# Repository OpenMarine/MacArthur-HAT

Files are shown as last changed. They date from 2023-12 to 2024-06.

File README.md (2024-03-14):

# MacArthur-HAT

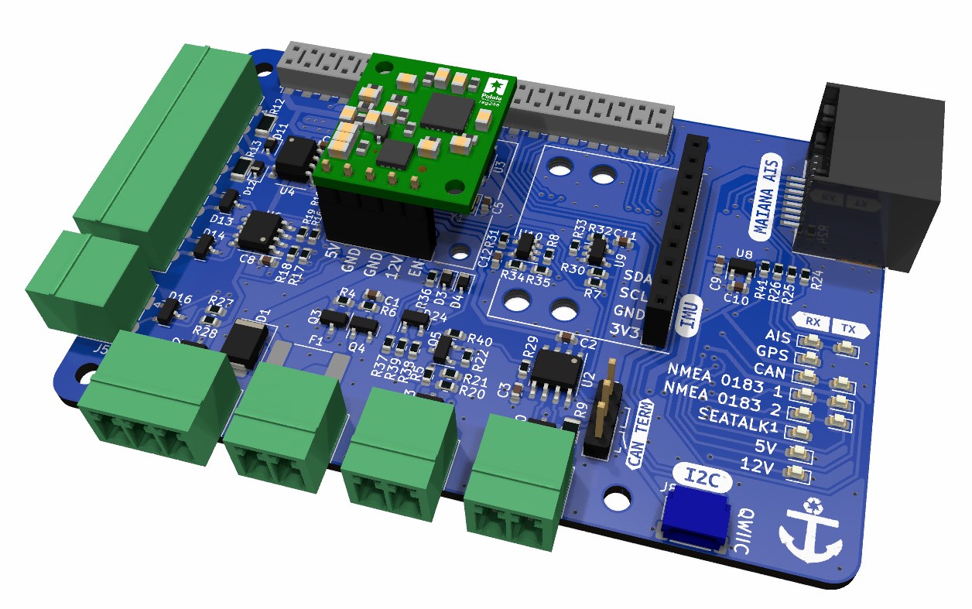
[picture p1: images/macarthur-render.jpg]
MacArthur-HAT


After a few years of developing software for **OpenPlotter**, we have identified exactly what we need in terms of hardware to achieve our goals and the result is the **MacArthur HAT** (Hardware Attached on Top), an add-on board for **Raspberry Pi** running OpenPlotter. With this HAT we want to get the fully open-source boat to free ourselves from dependence on big companies and make our boats more respectful with the environment.

> __Note__
>
> KiCad files will be released when the board is in production.

> __Documentation__
>
> http://macarthur-hat-documentation.rtfd.io

> __Buy__
>
> [**OpenMarine store** (Catalonia)](https://shop.openmarine.net/home/23-macarthur-hat.html)
> 
> [**Wegmatt store** (US)](https://shop.wegmatt.com/collections/openmarine)

> __Support__
>
> https://forum.openmarine.net/forumdisplay.php?fid=29

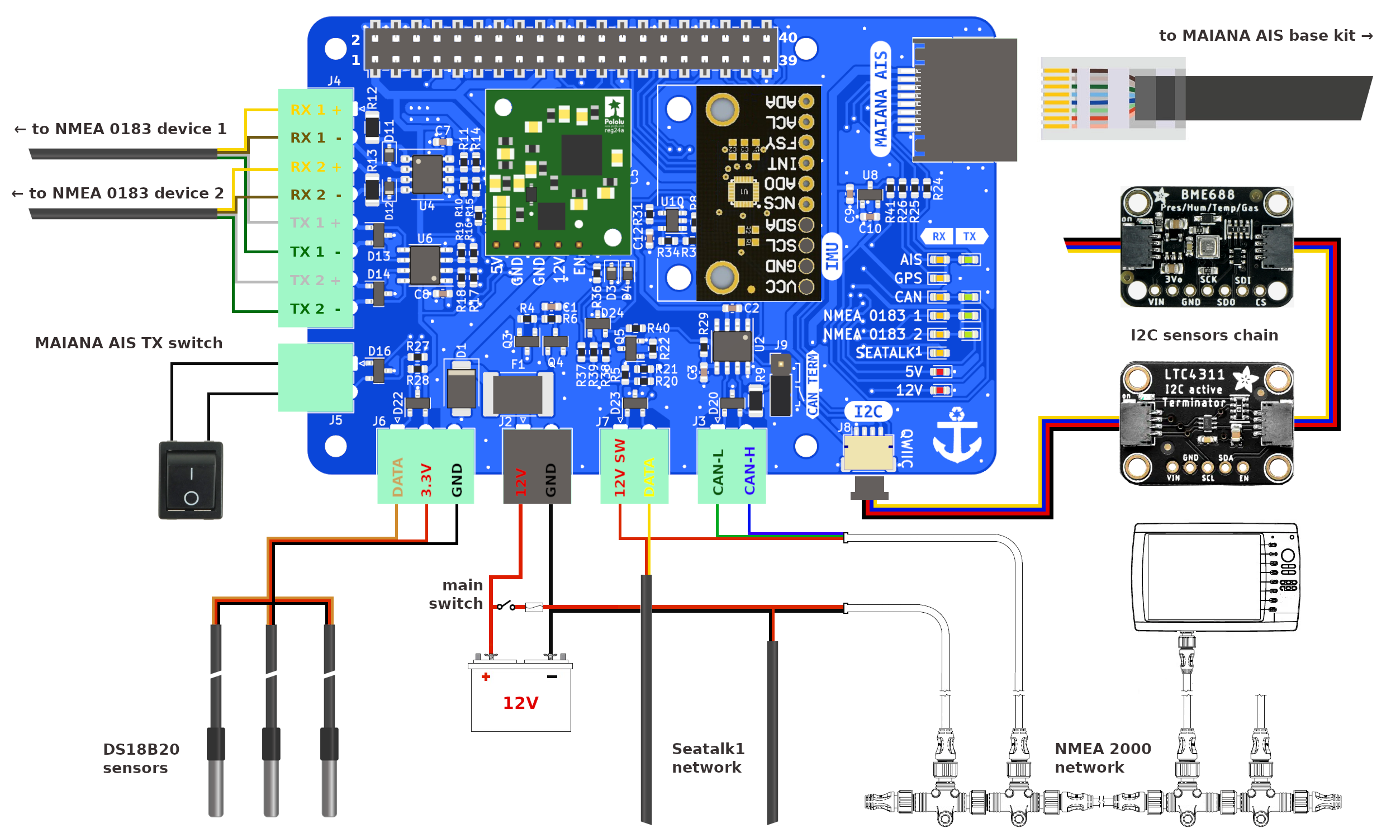
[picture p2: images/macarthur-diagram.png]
MacArthur-HAT


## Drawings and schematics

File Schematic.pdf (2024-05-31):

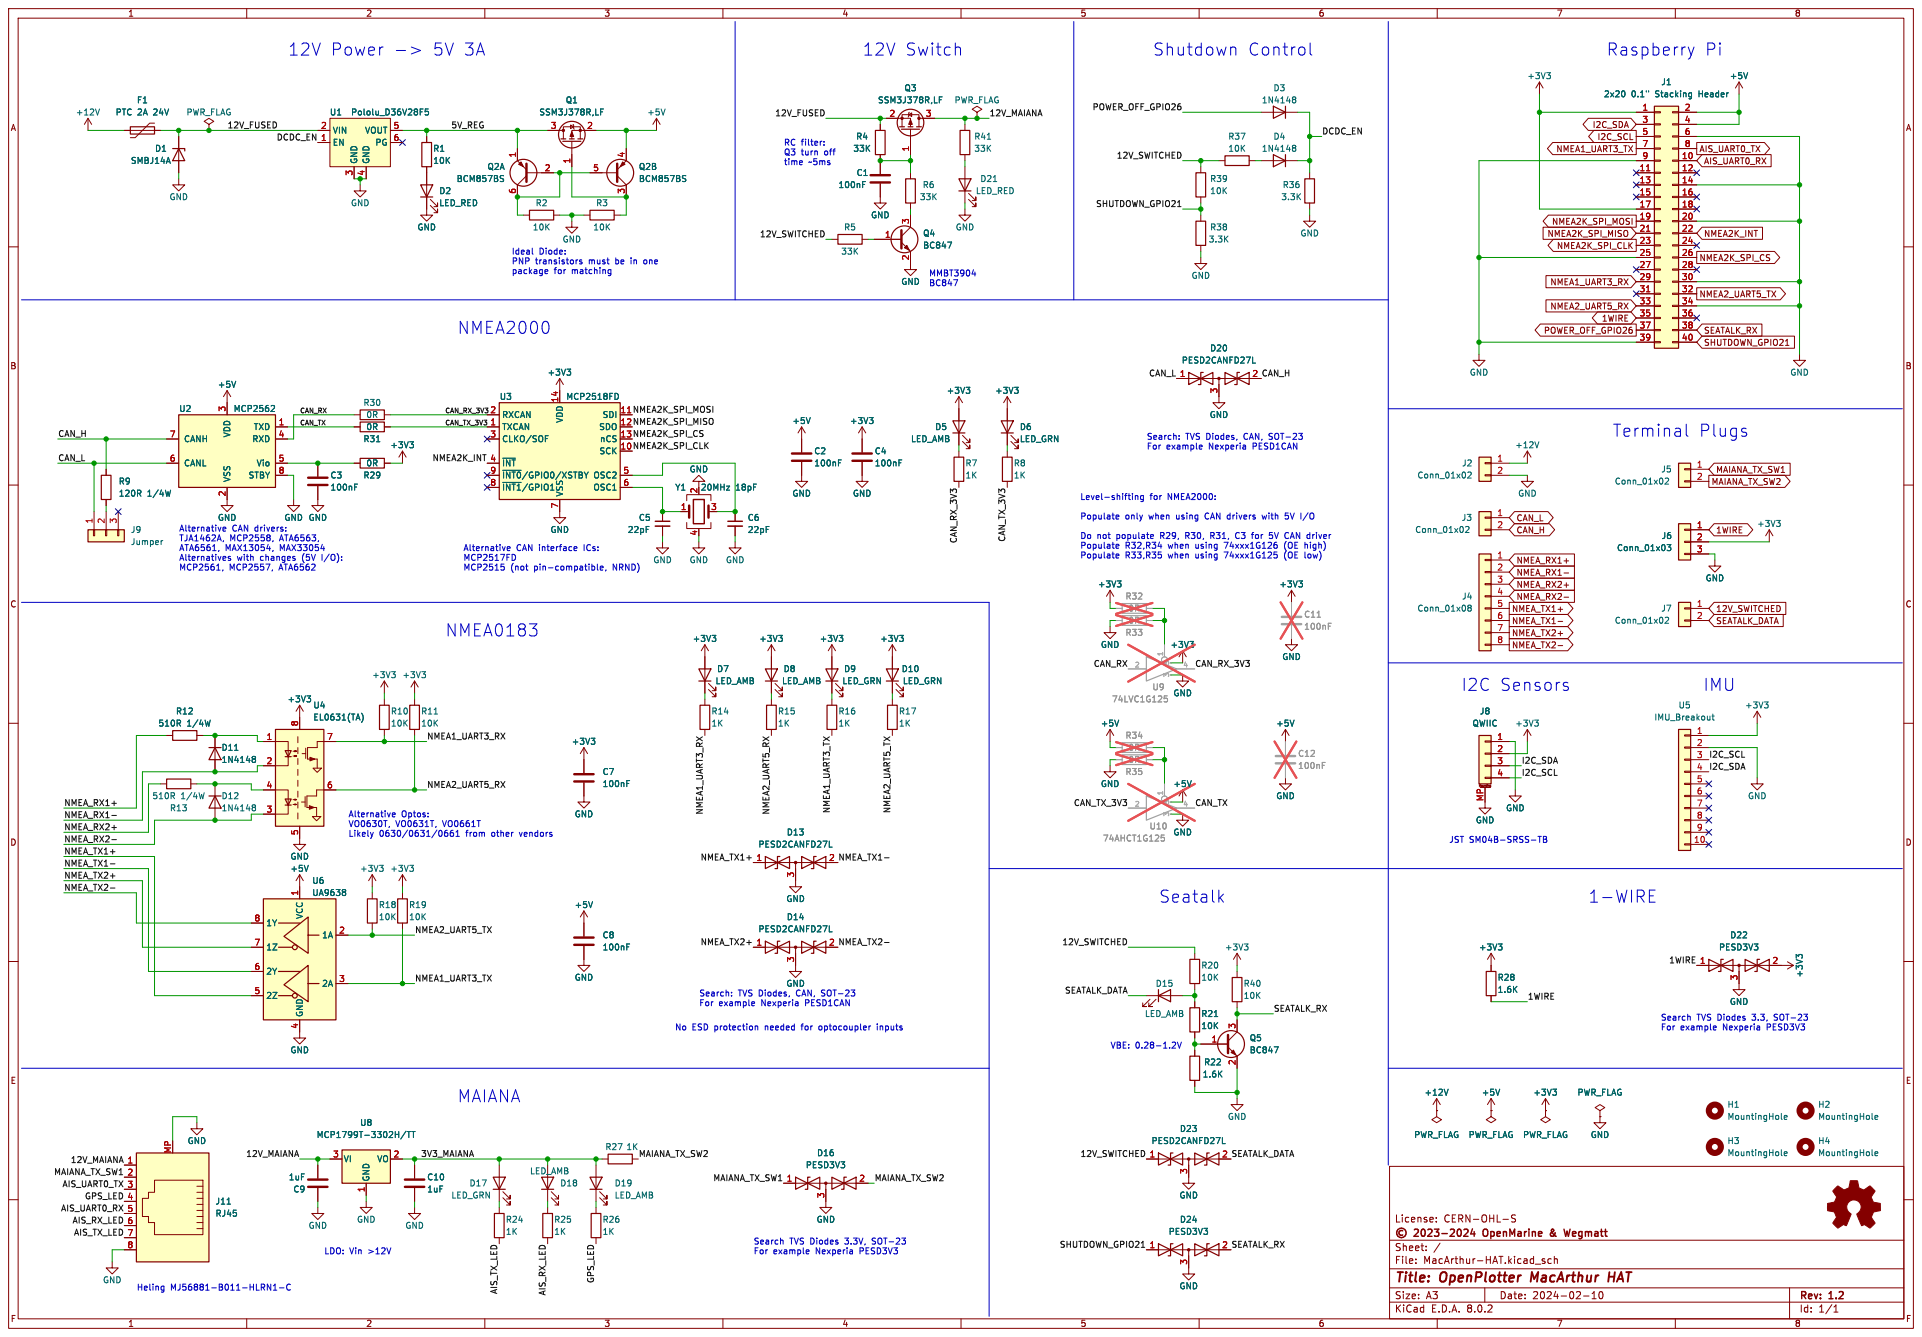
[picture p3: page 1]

Search: TVS Diodes, CAN, SOT-23 For example Nexperia PESD1CAN 12V Power -> 5V 3A

RC filter: Q3 turn off

3 RXD 4 Vio 5 CANL 6 CANH 7 STBY 8 GND GND GND GND

Search: TVS Diodes, CAN, SOT-23 For example Nexperia PESD1CAN NMEA2000

3 RXD 4 Vio 5 CANL 6 CANH 7 STBY 8 U2 MCP2562 +5V R29

Search TVS Diodes 3.3, SOT-23 For example Nexperia PESD3V3 Search TVS Diodes 3.3V, SOT-23 For example Nexperia PESD3V3

Id: 1/1 Title: OpenPlotter MacArthur HAT

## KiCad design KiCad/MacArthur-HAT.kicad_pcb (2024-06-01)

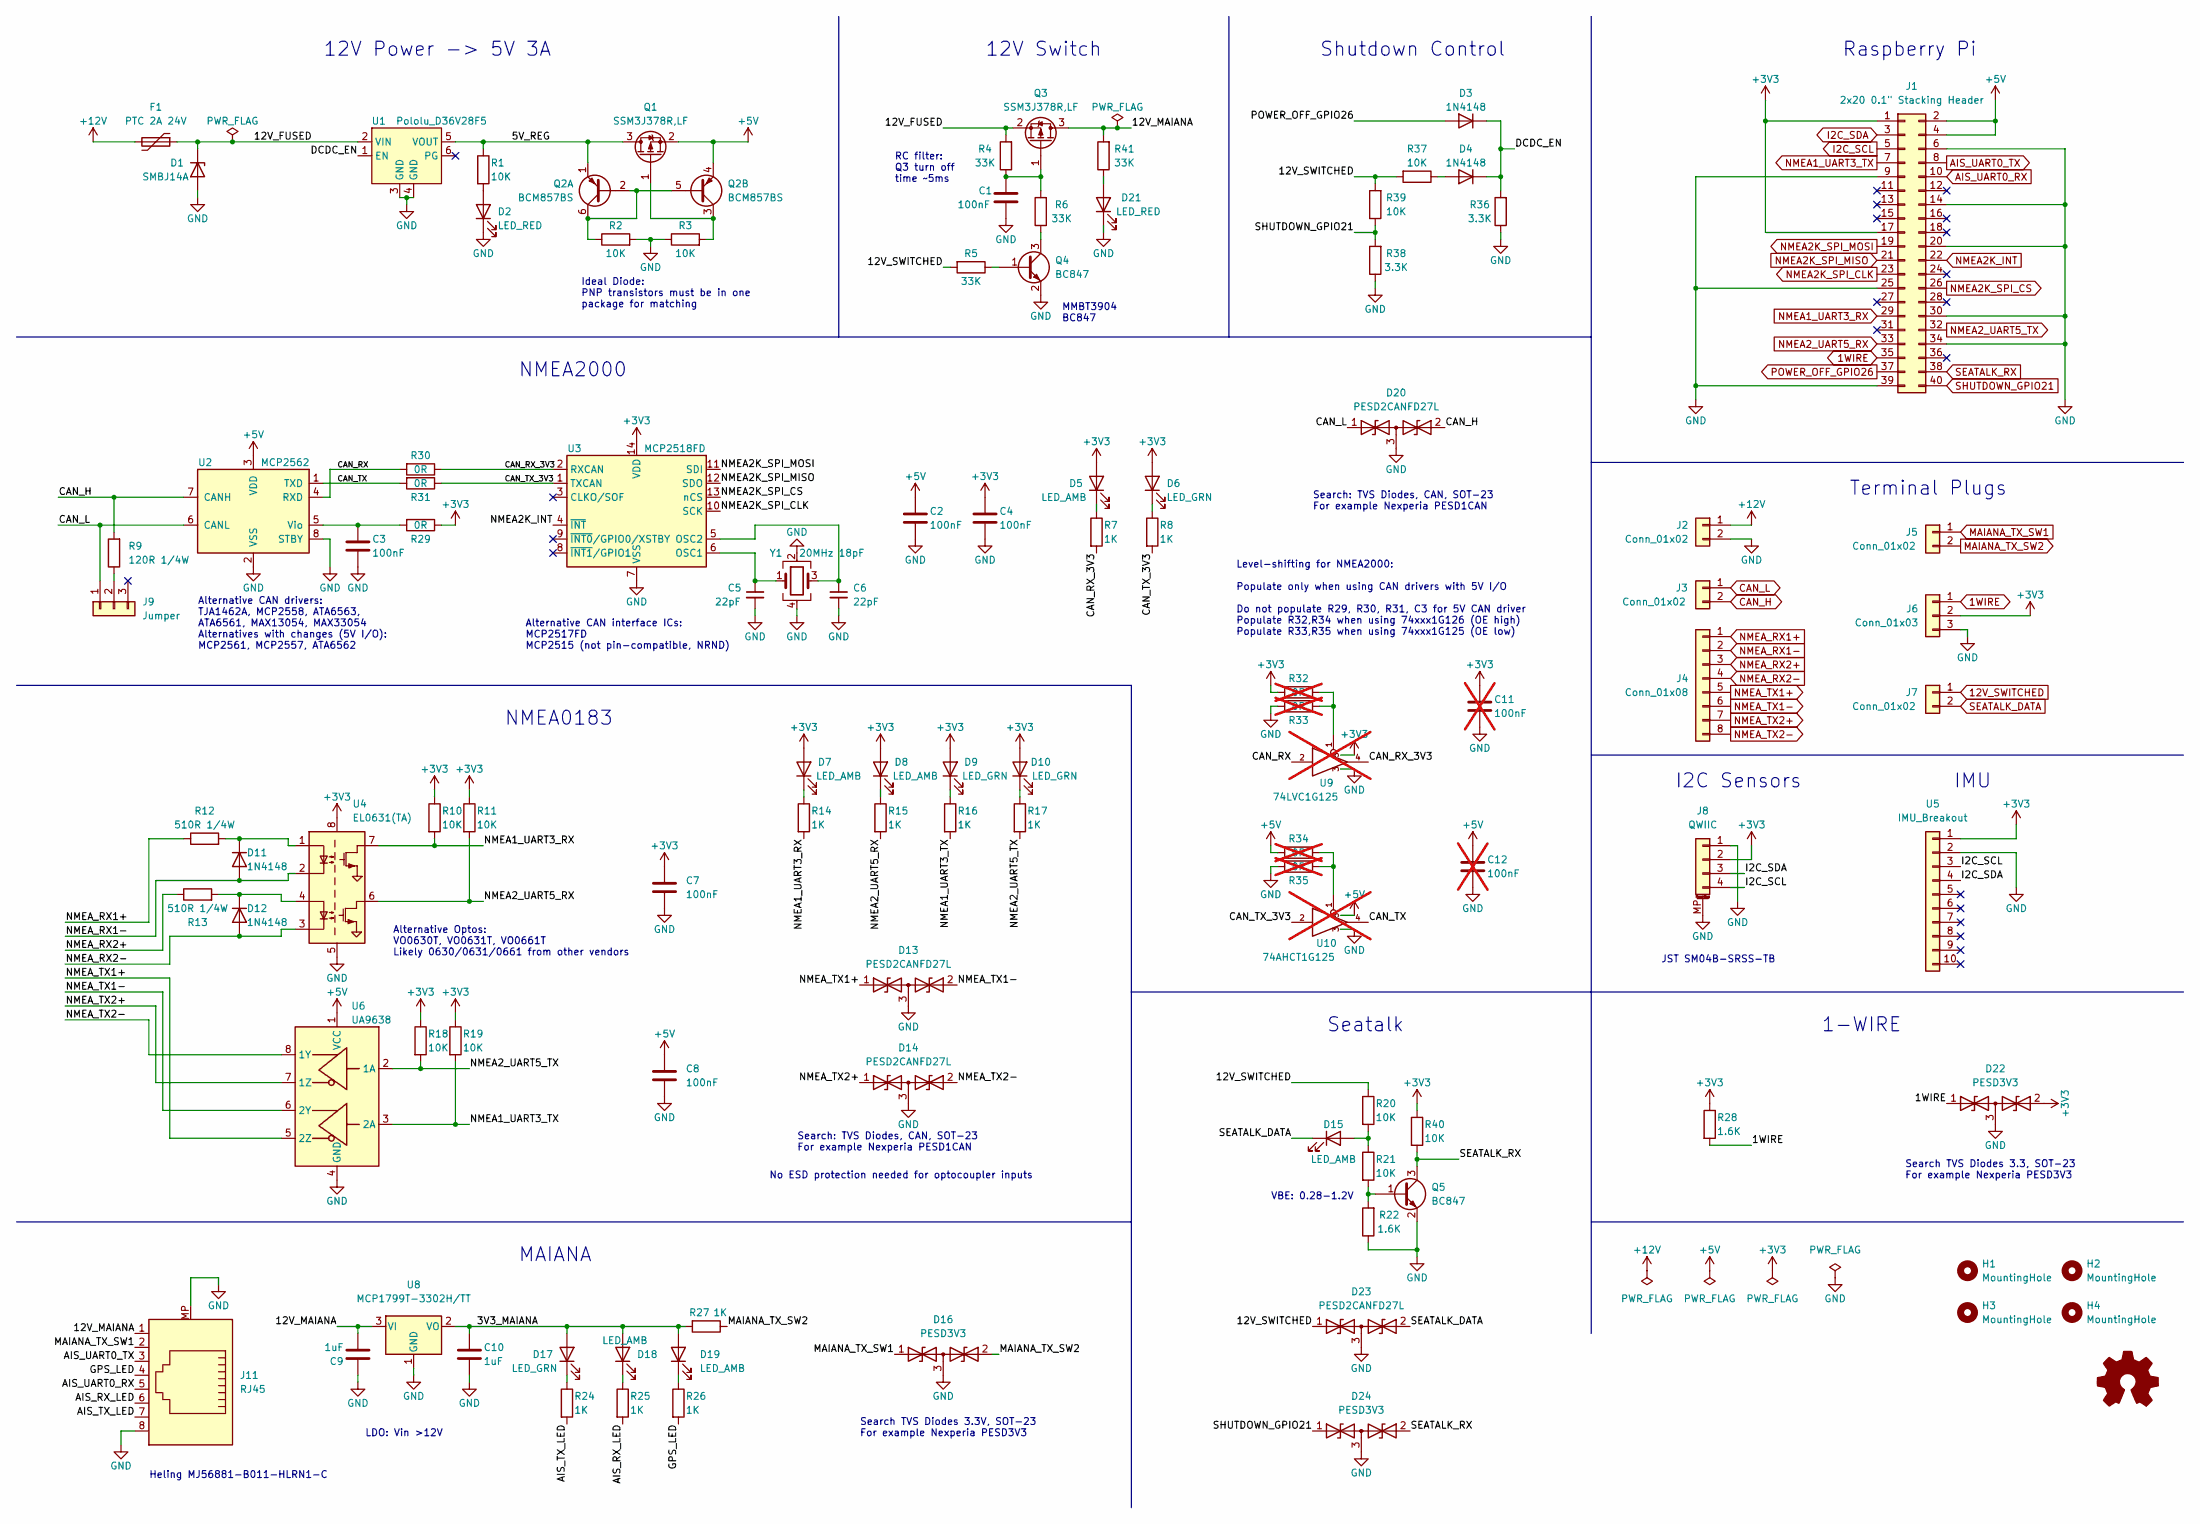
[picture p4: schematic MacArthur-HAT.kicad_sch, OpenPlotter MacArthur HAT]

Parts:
C1, C2, C3, C4, C7, C8: 100nF; C_0603_1608Metric
C5, C6: 22pF; C_0603_1608Metric
C9, C10: 1uF; C_0603_1608Metric
C11, C12: 100nF; C_0603_1608Metric; not fitted
D1: SMBJ14A; D_SMB; MPN SMBJ14A
D2, D21: LED_RED; LED_0603_1608Metric
D3, D4, D11, D12: 1N4148; D_SOD-323; MPN 1N4148WS
D5, D7, D8, D15, D18, D19: LED_AMB; LED_0603_1608Metric
D6, D9, D10, D17: LED_GRN; LED_0603_1608Metric
D13, D14, D20, D23: PESD2CANFD27L; SOT-23; MPN PESD2CAN
D16, D22, D24: PESD3V3; SOT-23; MPN PESD3V3S2UT,215
F1: PTC 2A 24V; Fuse_2920_7451Metric; MPN BSMD2920-200-24V
H1, H2, H3, H4: MountingHole; MountingHole_2.7mm_M2.5
J1: 2x20 0.1" Stacking Header; Raspberry_Pi_Stacking_Header
J2, J3, J5, J7: Conn_01x02; PhoenixContact_MC_1,5_2-G-3.5_1x02_P3.50mm_Horizontal
J4: Conn_01x08; PhoenixContact_MC_1,5_8-G-3.5_1x08_P3.50mm_Horizontal
J6: Conn_01x03; PhoenixContact_MC_1,5_3-G-3.5_1x03_P3.50mm_Horizontal
J8: QWIIC; JST_SH_SM04B-SRSS-TB_1x04-1MP_P1.00mm_Horizontal; MPN SM04B-SRSS-TB(LF)(SN)
J9: Jumper; PinHeader_1x03_P2.54mm_Vertical
J11: RJ45; RJ45-SMD_MJ56881-B011-HXRN1-C; MPN MJ56881-B011-HLRN1-C
LOGO1: Logo_Open_Hardware_Small; OSHW-Symbol_6.7x6mm_SilkScreen
Q1, Q3: SSM3J378R,LF; SOT-23; MPN SSM3J378R,LF
Q2: BCM857BS; SOT-363_SC-70-6; MPN BCM857BS
Q4, Q5: BC847; SOT-23; MPN BC847
R1, R2, R3, R10, R11, R18, R19, R20, R21, R37, R39, R40: 10K; R_0603_1608Metric
R4, R5, R6, R41: 33K; R_0603_1608Metric
R7, R8, R14, R15, R16, R17, R24, R25, R26, R27: 1K; R_0603_1608Metric
R9: 120R 1/4W; R_1206_3216Metric
R12, R13: 510R 1/4W; R_1206_3216Metric
R22, R28: 1.6K; R_0603_1608Metric
R29, R30, R31: 0R; R_0603_1608Metric
R32, R33, R34, R35: 0R; R_0603_1608Metric; not fitted
R36, R38: 3.3K; R_0603_1608Metric
U1: Pololu_D36V28F5; Pololu_D36V28Fx_reverse
U2: MCP2562; SOIC-8_3.9x4.9mm_P1.27mm; MPN MCP2562
U3: MCP2518FD; SOIC-14_3.9x8.7mm_P1.27mm; MPN MCP2518FD
U4: EL0631(TA); SOIC-8H_3.9x5.8mm_P1.27mm; MPN EL0631(TA)
U5: IMU_Breakout; CJMCU-96802-20948
U6: UA9638; SOIC-8_3.9x4.9mm_P1.27mm; MPN UA9638
U8: MCP1799T-3302H/TT; SOT-23; MPN MCP1799T-3302H/TT
U9: 74LVC1G125; SOT-23-5; not fitted
U10: 74AHCT1G125; SOT-23-5; not fitted
Y1: 20MHz 18pF; Crystal_SMD_3225-4Pin_3.2x2.5mm

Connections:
1WIRE: D22.1 (A1), J1.35, J6.1, R28.2
12V_SWITCHED: D23.1 (A1), J7.1, R5.2, R20.1, R37.2, R39.2
+3V3: C4.1, C7.1, C11.1, D5.2 (A), D6.2 (A), D7.2 (A), D8.2 (A), D9.2 (A), D10.2 (A), D22.2 (A2), J1.1, J1.17, J6.2, J8.2, R10.1, R11.1, R18.1, R19.1, R28.1, R29.1, R32.2, R40.1, U3.14 (VDD), U4.8 (VCC), U5.1, U9.5
+5V: C2.1, C8.1, C12.1, J1.2, J1.4, Q1.2 (S), Q2.4 (E2), R34.2, U2.3 (VDD), U6.1 (VCC), U10.5
+12V: F1.2, J2.1
/3V3_MAIANA: C10.1, D17.2 (A), D18.2 (A), D19.2 (A), R27.2, U8.2 (VO)
/5V_REG: Q1.3 (D), Q2.1 (E1), R1.1, U1.5 (VOUT)
/12V_FUSED: D1.1 (K), F1.1, Q3.2 (S), R4.2, U1.2 (VIN)
/12V_MAIANA: C9.2, J11.1, Q3.3 (D), R41.2, U8.3 (VI)
/AIS_RX_LED: J11.6, R25.2
/AIS_TX_LED: J11.7, R24.2
/CAN_RX: R30.2, U2.4 (RXD), U9.2
/CAN_RX_3V3: R7.2, R30.1, U3.2 (RXCAN), U9.4
/CAN_TX: R31.2, U2.1 (TXD), U10.4
/CAN_TX_3V3: R8.2, R31.1, U3.1 (TXCAN), U10.2
/DCDC_EN: D3.1 (K), D4.1 (K), R36.2, U1.1 (EN)
/GPS_LED: J11.4, R26.2
AIS_UART0_RX: J1.10, J11.5
AIS_UART0_TX: J1.8, J11.3
CAN_H: D20.2 (A2), J3.2, R9.2, U2.7 (CANH)
CAN_L: D20.1 (A1), J3.1, J9.1, U2.6 (CANL)
GND: C1.2, C2.2, C3.2, C4.2, C5.2, C6.2, C7.2, C8.2, C9.1, C10.2, C11.2, C12.2, D1.2 (A), D2.1 (K), D13.3 (common), D14.3 (common), D16.3 (common), D20.3 (common), D21.1 (K), D22.3 (common), D23.3 (common), D24.3 (common), J1.6, J1.9, J1.14, J1.20, J1.25, J1.30, J1.34, J1.39, J2.2, J6.3, J8.1, J8.MP (MountPin), J11.8, J11.MP, Q4.2 (E), Q5.2 (E), R2.2, R3.1, R22.1, R33.1, R35.1, R36.1, R38.1, U1.3 (GND), U1.4 (GND), U2.2 (VSS), U2.8 (STBY), U3.7 (VSS), U3.15 (VSS), U4.5 (GND), U5.2, U6.4 (GND), U8.1 (GND), U9.3, U10.3, Y1.2, Y1.4
I2C_SCL: J1.5, J8.4, U5.3
I2C_SDA: J1.3, J8.3, U5.4
MAIANA_TX_SW1: D16.1 (A1), J5.1, J11.2
MAIANA_TX_SW2: D16.2 (A2), J5.2, R27.1
NMEA1_UART3_RX: J1.29, R10.2, R14.2, U4.7 (VO1)
NMEA1_UART3_TX: J1.7, R16.2, R19.2, U6.3 (2A)
NMEA2K_INT: J1.22, U3.4 (~INT)
NMEA2K_SPI_CLK: J1.23, U3.10 (SCK)
NMEA2K_SPI_CS: J1.26, U3.13 (nCS)
NMEA2K_SPI_MISO: J1.21, U3.12 (SDO)
NMEA2K_SPI_MOSI: J1.19, U3.11 (SDI)
NMEA2_UART5_RX: J1.33, R11.2, R15.2, U4.6 (VO2)
NMEA2_UART5_TX: J1.32, R17.2, R18.2, U6.2 (1A)
NMEA_RX1+: J4.1, R12.1
NMEA_RX1-: D11.2 (A), J4.2, U4.2 (C1)
NMEA_RX2+: J4.3, R13.1
NMEA_RX2-: D12.2 (A), J4.4, U4.3 (C2)
NMEA_TX1+: D13.1 (A1), J4.5, U6.5 (2Z)
NMEA_TX1-: D13.2 (A2), J4.6, U6.6 (2Y)
NMEA_TX2+: D14.1 (A1), J4.7, U6.7 (1Z)
NMEA_TX2-: D14.2 (A2), J4.8, U6.8 (1Y)
unnamed: D2.2 (A), R1.2
unnamed: D4.2 (A), R37.1
unnamed: D5.1 (K), R7.1
unnamed: D6.1 (K), R8.1
unnamed: D7.1 (K), R14.1
unnamed: D8.1 (K), R15.1
unnamed: D9.1 (K), R16.1
unnamed: D10.1 (K), R17.1
unnamed: D11.1 (K), R12.2, U4.1 (A1)
unnamed: D12.1 (K), R13.2, U4.4 (A2)
unnamed: D15.2 (A), R20.2, R21.1
unnamed: D17.1 (K), R24.1
unnamed: D18.1 (K), R25.1
unnamed: D19.1 (K), R26.1
unnamed: D21.2 (A), R41.1
unnamed: J9.2, R9.1
unnamed: Q1.1 (G), Q2.3 (C2), R3.2
unnamed: Q2.2 (B1), Q2.5 (B2), Q2.6 (C1), R2.1
unnamed: C1.1, Q3.1 (G), R4.1, R6.2
unnamed: Q4.1 (B), R5.1
unnamed: Q4.3 (C), R6.1
unnamed: Q5.1 (B), R21.2, R22.2
unnamed: R32.1, R33.2, U9.1
unnamed: R34.1, R35.2, U10.1
unnamed: C3.1, R29.2, U2.5 (Vio)
unnamed: C5.1, U3.6 (OSC1), Y1.1
unnamed: C6.1, U3.5 (OSC2), Y1.3
POWER_OFF_GPIO26: D3.2 (A), J1.37
SEATALK_DATA: D15.1 (K), D23.2 (A2), J7.2
SEATALK_RX: D24.2 (A2), J1.38, Q5.3 (C), R40.2
SHUTDOWN_GPIO21: D24.1 (A1), J1.40, R38.2, R39.1

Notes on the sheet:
IMU
Alternative CAN interface ICs: MCP2517FD MCP2515 (not pin-compatible, NRND)
I2C Sensors
Raspberry Pi
RC filter: Q3 turn off time ~5ms
Ideal Diode: PNP transistors must be in one package for matching
JST SM04B-SRSS-TB
Alternative CAN drivers: TJA1462A, MCP2558, ATA6563, ATA6561, MAX13054, MAX33054 Alternatives with changes (5V I/O): MCP2561, MCP2557, ATA6562
Level-shifting for NMEA2000: Populate only when using CAN drivers with 5V I/O Do not populate R29, R30, R31, C3 for 5V CAN driver Populate R32,R34 when using 74xxx1G126 (OE high) Populate R33,R35 when using 74xxx1G125 (OE low)
Search TVS Diodes 3.3, SOT-23 For example Nexperia PESD3V3
MMBT3904 BC847
NMEA0183
Alternative Optos: VO0630T, VO0631T, VO0661T Likely 0630/0631/0661 from other vendors
No ESD protection needed for optocoupler inputs
Search: TVS Diodes, CAN, SOT-23 For example Nexperia PESD1CAN
1-WIRE
Heling MJ56881-B011-HLRN1-C
NMEA2000
Search TVS Diodes 3.3V, SOT-23 For example Nexperia PESD3V3
LDO: Vin >12V
VBE: 0.28-1.2V
12V Switch
Shutdown Control
12V Power -> 5V 3A
MAIANA
Terminal Plugs
Seatalk

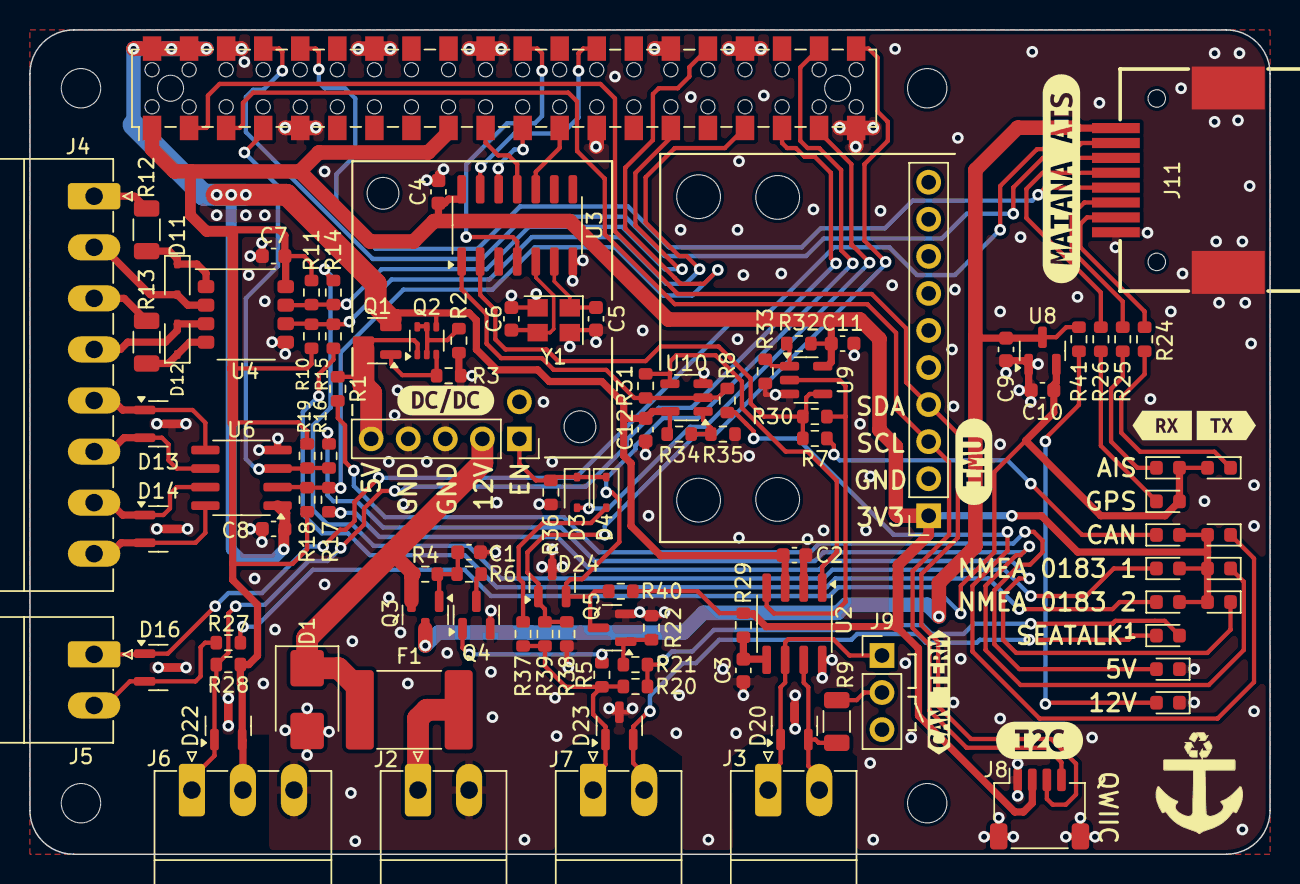
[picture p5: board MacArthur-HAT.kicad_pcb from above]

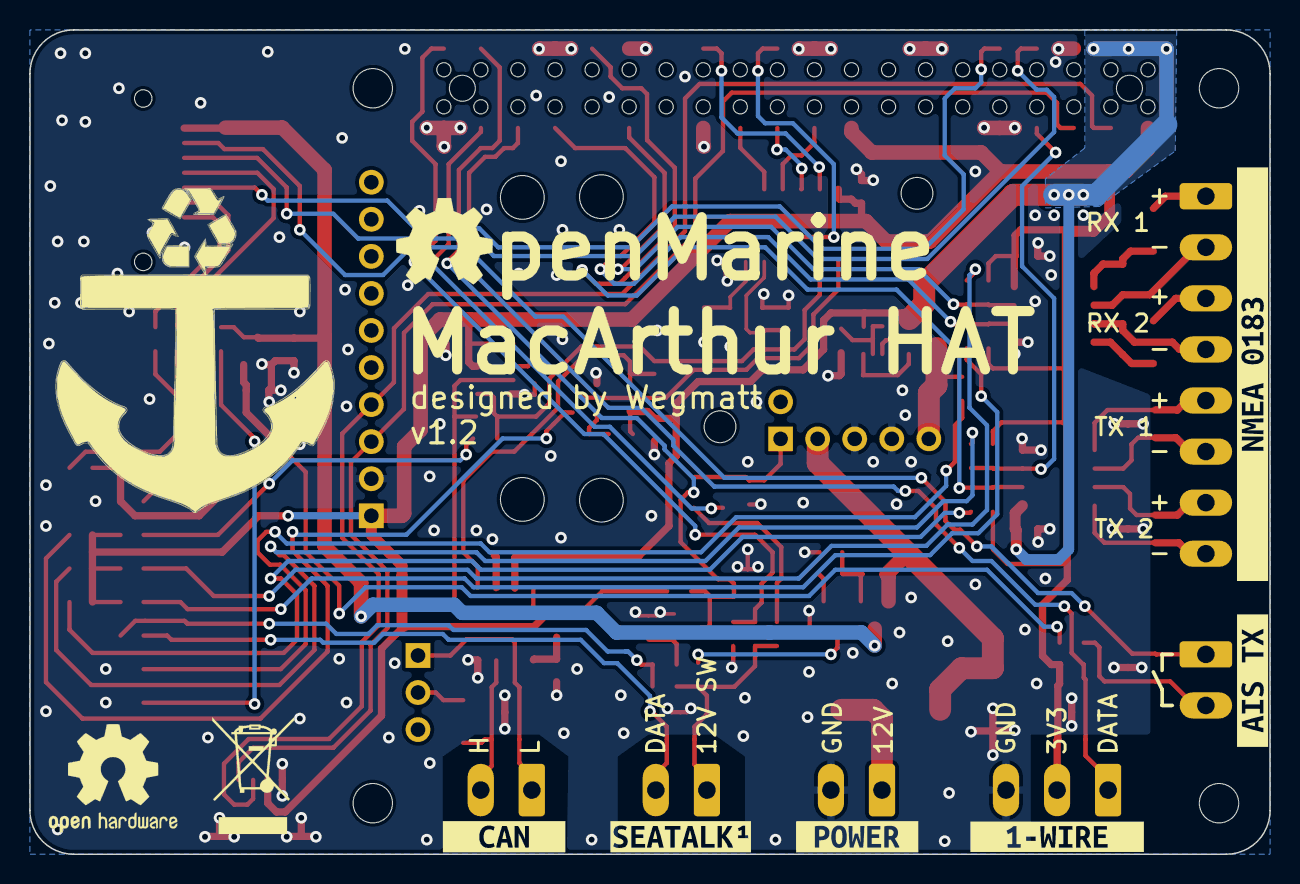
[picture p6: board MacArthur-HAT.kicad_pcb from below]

Board: 4 copper layers, 85.0 x 56.5 mm, 120 parts (7 on the bottom side), 74 nets.

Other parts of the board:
kibuzzard-63BC76FF: G***; kibuzzard-63BC76FF
kibuzzard-63BC7717: G***; kibuzzard-63BC7717
kibuzzard-637EF3F9: G***; kibuzzard-637EF3F9
kibuzzard-637EF437: G***; kibuzzard-637EF437
kibuzzard-637EF583: G***; kibuzzard-637EF583
kibuzzard-637EFEBF: G***; kibuzzard-637EFEBF
kibuzzard-637EFF6C: G***; kibuzzard-637EFF6C
kibuzzard-637F0005: G***; kibuzzard-637F0005
kibuzzard-637FCC15: G***; kibuzzard-637FCC15
kibuzzard-637FCC47: G***; kibuzzard-637FCC47
kibuzzard-637FCC76: G***; kibuzzard-637FCC76
kibuzzard-637FCC90: G***; kibuzzard-637FCC90
kibuzzard-646FE67F: G***; kibuzzard-646FE67F

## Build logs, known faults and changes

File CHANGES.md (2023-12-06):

## v1.2 - 2023/10/29

- upgrade to KiCad 7.
- changed 1-Wire pull-up from 3.3k to 1.6k.
- changed Seatalk R22 from 3.3k to 1.6k.
- changed the RJ45 connector from through-hole to surface mount.

## v1.1 - 2023/06/17

- Rebuilt Seatalk1 circuit replacing opto with a transistor to make it work in all cases.
- Removed Seatalk1 jumper.
- New screw terminal configuration to make wiring clearer and more consistent.
- Removed option to power from NMEA 2000 or Seatalk1 networks to meet standards.
- Relocation of the I2C connector on the front side for easy access.
- Added 3.3V ESD diodes to Seatalk RX and Shutdown-detection to protect Pi GPIOs.
- Changed 1-Wire ESD diodes from 5V to 3.3V.
- Changed from 3.3K to 1K resistor to make amber LEDs brighter.
- Tweaked a few resistor values to minimize number of different parts.
- The CAN termination resistor changed from 1/10W to 1/4W.
- Rebuilt 12V switch circuit to use MOSFET for controlling power from main 12V input to MAIANA.

## v1.0 - 2023/03/21

- First version for testers

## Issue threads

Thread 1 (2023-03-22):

Why not whole box on CM4?

mgrouch, 2023-03-22:
Why not to make it more polished product
and design it as a PCB for CM4 with matching
case (enclosure). When all hardware is known
it would be not difficult to customize software image for it. Let’s say based on the way BBN Marine OS is built and then it would be complete package. Hardware, enclosure, cables and software image to load. Front panel with power switch (momentary for graceful shutdown), few USB ports, audio in/out, status lights via semitransparent plastic, SD card slot with plastic cap.  All other ports on back panel. And a way to mount device flush to a boat panel.
It would be more attractive to average user.

Thanks

Closed 2024-05-01.

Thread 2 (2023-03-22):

Issue with putting IMU inside box

mgrouch, 2023-03-22:
IMU needs to be calibrated and placed in certain way. To calibrate it it needs to be rotated in many ways. Recalibration might be needed periodically. Due to that it makes sense to have IMU in a small waterproof box separately connected via i2c.
I think no need to put IMU inside hard mounted to this HAT.
That separate small box with IMU needs to be easily dismountable.

Thanks

Closed 2024-05-01.

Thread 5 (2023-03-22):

No audio input

mgrouch, 2023-03-22:
Audio input is useful on a boat to
decode from SSB radio for examples.
some CM4 boards provide audio input.
pi4 itself doesn’t have audio in.
thanks

Closed 2024-05-01.

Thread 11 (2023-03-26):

Separate device instead of hat.

mgrouch, 2023-03-26:
I think hat design is too much of vendor lock-in for users.

 It would be better to have an open source, open hardware multiplexer box.
with few NMEA 0183, one NMEA 2000, Seatalk
and USB and Ethernet (tcp, udp) to connect to pi. Might be box with MCU (esp32 or something).

Whole thing with waterproof box and proper ip67 connectors.

Then might be some other simpler hat for pi with i2c, Victron connector, few temp sensors connectors, maiana (plug and button interface), uart plug for pypilot motor controller, RTC clock, powering pi from 12/24v.
Audio card with audio in/out (maybe).
(Optional LoRa module?)

All NMEA coming from separate device via usb or Ethernet.

Thanks

mgrouch, 2023-04-11:
My experience tells me that targeted audience needs a ready to plug device. Those people just do not have time to deal with hats.
they need a device and simple easy to follow setup instructions.

masonleschyna, 2023-12-01:
I agree with this idea. Make a sensor hub with a single standard output. USB could work but you could also use NMEA OneNet. This HAT would theb serve as a gateway to the onboard sensors for devices connected via USB or LAN.

mgrouch, 2023-12-01:
> I agree with this idea. Make a sensor hub with a single standard output. USB could work but you could also use NMEA OneNet. This HAT would theb serve as a gateway to the onboard sensors for devices connected via USB or LAN.

There some solutions (still half baked and non open source).

I can mention

Victron CerboGX sensors support,

Pitufino NMEA gateway

ESP32 Sailor Hat

CX5003 nmea2000 module

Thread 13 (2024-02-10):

Share gerber files

kagouraki, 2024-02-10:
Will you share the gerber files so some of us can make the boards our selfs? Today you launched the hat and after 5 minutes you took the website down... who knows if there are boards left and when they will be available again :(
Very good work though !

sailoog, 2024-02-11:
Sorry for the server problem, too much demand, the server is up again and you can still find some units for sale.

We will still wait a bit to publish the Kicad files. First we want to recover the money invested and get some extra resources to stabilize the stock. We will then publish the files so that people can modify and adapt the HAT.

sailoog, 2024-06-01:
Closed by https://github.com/OpenMarine/MacArthur-HAT/commit/a109cf125e574781115fbb9ef189cf731384045f

Closed 2024-06-01.

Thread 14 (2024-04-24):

NMEA 2000 non-isolated input and output and ground loops

mgrouch, 2024-04-24:
NMEA 2000 on this hat has non-isolated input and output. Will it create issues with
ground loops?

thanks

sailoog, 2024-04-24:
https://macarthur-hat-documentation.readthedocs.io/en/latest/nmea2000.html

mgrouch, 2024-04-24:
What can happen if someone plugs in pi from shore power and NMEA 2000 network is powered from a battery?

thanks

sailoog, 2024-04-24:
And that is why manuals and instructions exist.

Closed 2024-05-01.

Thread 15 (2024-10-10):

CAN hangs on pi 4 after last raspi upgrades.

hwater, 2024-10-10:
if the can line is uncommented in config.txt the pi runs again - of course without canbus.

regards - holger

hwater, 2024-10-10:
if the can line is uncommented in config.txt the pi runs again - of course without canbus.

sailoog, 2024-10-26:
closed by https://forum.openmarine.net/showthread.php?tid=5740&pid=31811#pid31811

Closed 2024-10-26.

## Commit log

2023-06-15 new schematic
2023-10-29 update schematic
2024-05-09 Switch to online docs
2024-06-01 unzip kicad files
    [MacArthur-HAT.kicad_pcb, MacArthur-HAT.kicad_sch]

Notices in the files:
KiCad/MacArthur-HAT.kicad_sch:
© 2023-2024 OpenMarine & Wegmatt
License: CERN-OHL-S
